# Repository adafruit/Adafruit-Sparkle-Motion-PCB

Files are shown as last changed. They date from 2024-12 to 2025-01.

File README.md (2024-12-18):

## Adafruit Sparkle Motion - All-In-One WLED and xLights Board

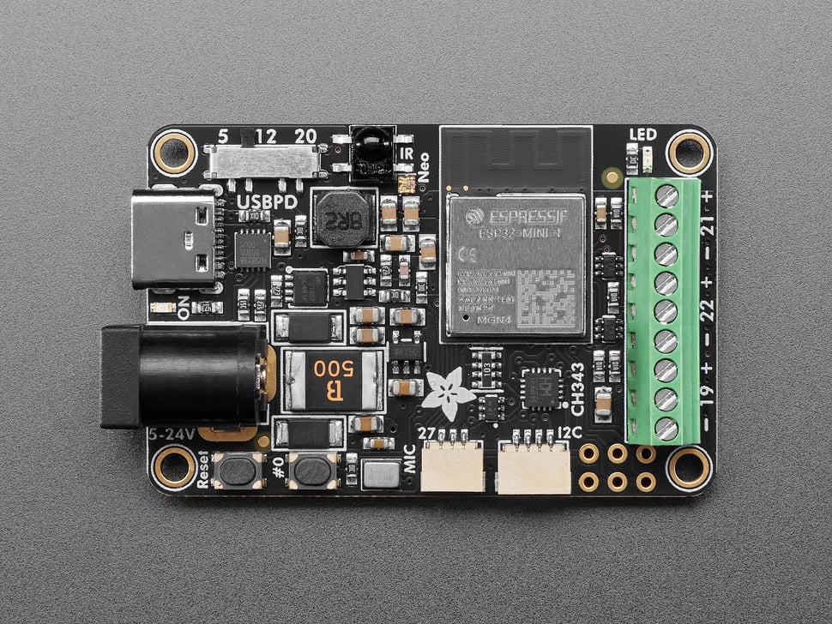
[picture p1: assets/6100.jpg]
<a href="http://www.adafruit.com/products/6100"><br/>
Click here to purchase one from the Adafruit shop</a>

PCB files for the Adafruit Sparkle Motion - All-In-One WLED and xLights Board

Format is EagleCAD schematic and board layout
* https://www.adafruit.com/product/6100

### Description

* Power via USB Type C PD with a slide switch that selects between 5, 12, and 20V (24V pixels can usually run fine at 20V) OR via a 2.1mm DC jack. With ideal diodes, it’s good for up to 5A from either.
* ESP32-Mini module with built-in or optional wFL antenna port. The classic ’32 has broad support, even if we’d prefer the ‘S2 or ‘S3.
* There are three output signal terminal block sets, with power and ground for each. They’ll be level-shifted to 5V.
* Built in I2S microphone (we’re still pondering this one).
* Stemma QT I2C port to connect external sensors/OLEDs/etc.; separate analog/digital input JST port.
* 1.3″x1.75″ / 33mm x 45mm size with mounting holes.

### License

Adafruit invests time and resources providing this open source design, please support Adafruit and open-source hardware by purchasing products from [Adafruit](https://www.adafruit.com)!

Designed by Limor Fried/Ladyada for Adafruit Industries.

Creative Commons Attribution/Share-Alike, all text above must be included in any redistribution. 
See license.txt for additional details.

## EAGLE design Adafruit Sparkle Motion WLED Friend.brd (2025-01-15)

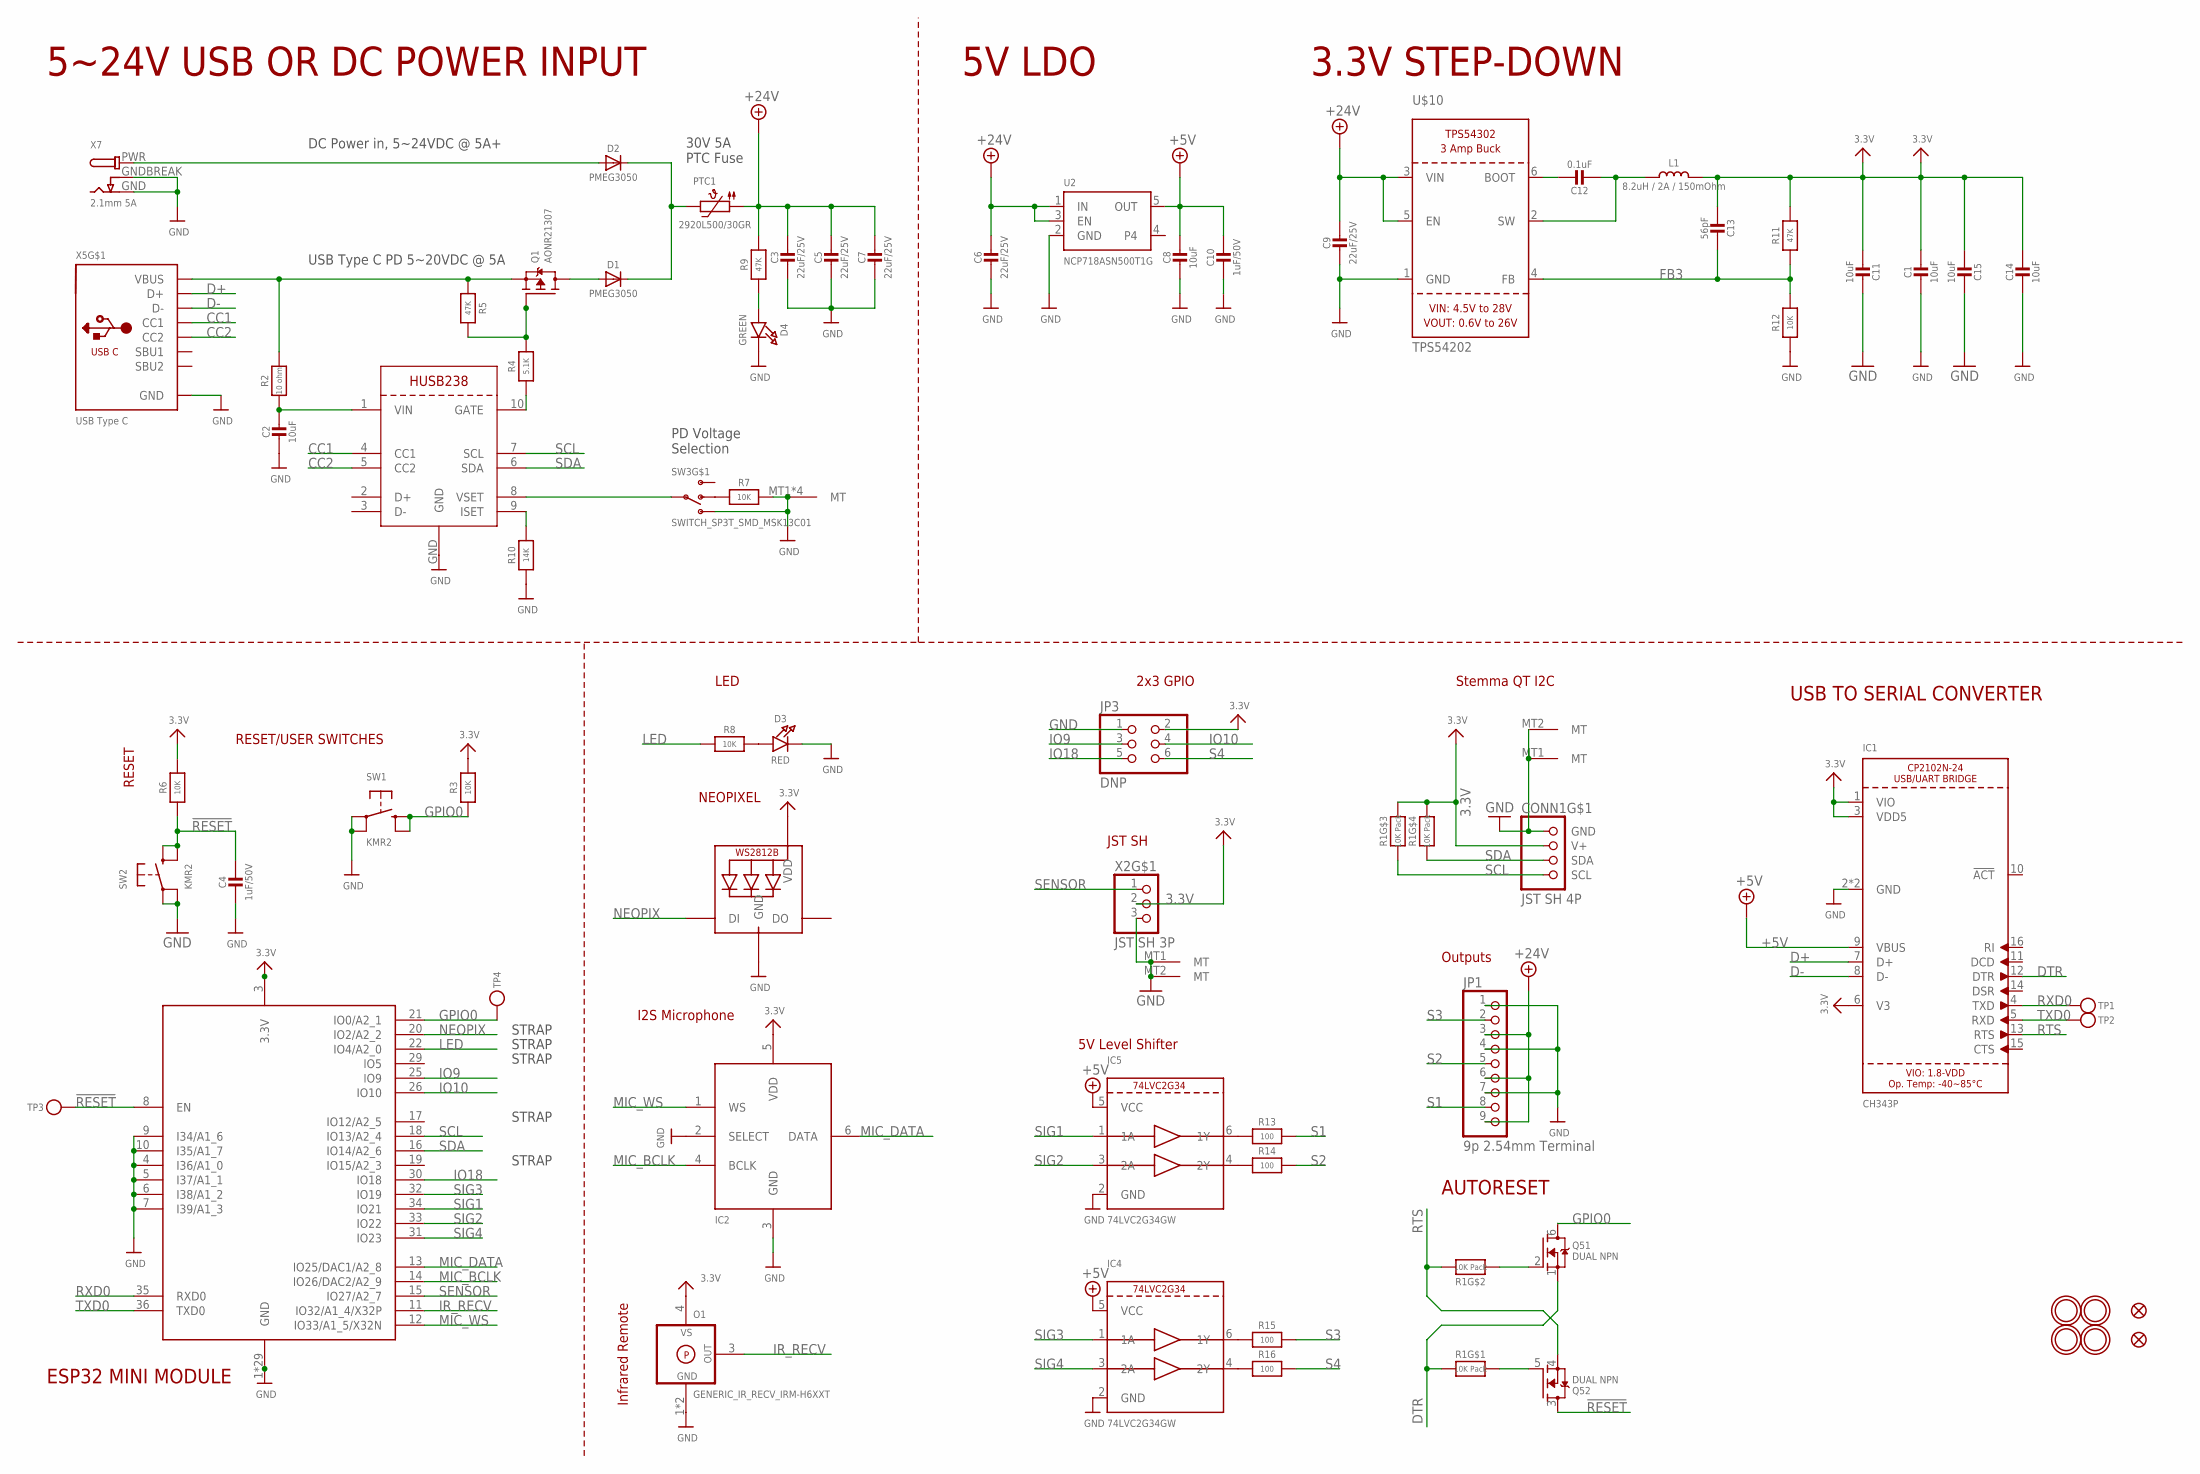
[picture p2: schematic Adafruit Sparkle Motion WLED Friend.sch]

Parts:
C1, C2, C8, C11, C14, C15: 10uF; 0805-NO
C3, C5, C6, C7, C9: 22uF/25V; 0805-NO
C4, C10: 1uF/50V; 0603-NO
C12: 0.1uF; 0603-NO
C13: 56pF; 0603-NO
CONN1: JST SH 4P; JST_SH4
D1, D2: PMEG3050; SOD-128
D3: RED; CHIPLED_0603_NOOUTLINE
D4: GREEN; CHIPLED_0603_NOOUTLINE
IC1: CH343P; QFN16_3MM
IC2: ICS-43434; SPH0645LM4H
IC4, IC5: 74LVC2G34GW; SC70-6L
JP1: 9p 2.54mm Terminal; 1X09_2.54MMTERMINAL
JP3: DNP; 2X03_ROUND_70MIL
L1: 8.2uH / 2A / 150mOhm; INDUCTOR_5X5MM_NR5040_NOTHERMALS
LED1: WS2812B_SK6805_1515; SK6805_1515
O1: GENERIC_IR_RECV_IRM-H6XXT; IRM-H6XXT
PTC1: 2920L500/30GR; PTC2920
Q1: AONR21307; POWERDI3333
Q5: DUAL NPN; SOT363; JLC_ROTATION 0
R1: 10K Pack; RESPACK_4X0603
R2: 10 ohm; 0603-NO
R3, R6, R7, R8, R12: 10K; 0603-NO
R4: 5.1K; 0603-NO
R5, R9, R11: 47K; 0603-NO
R10: 14K; 0603-NO
R13, R14, R15, R16: 100; 0603-NO
SW1, SW2: KMR2; BTN_RKB2_4.6X2.8
SW3: SWITCH_SP3T_SMD_MSK13C01; MSK-13C01
TP1, TP2, TP3, TP4: TESTPOINTROUND1.5MM; TESTPOINT_ROUND_1.5MM
U2: NCP718ASN500T1G; SOT23-5; JLC_ROTATION 0
U$10: TPS54202; SOT23-6
U$14, U$20, U$28, U$31: MOUNTINGHOLE2.5; MOUNTINGHOLE_2.5_PLATED
U$34, U$35: FIDUCIAL_1MM
X2: JST SH 3P; JST_SH3
X3: HUSB238; DFN10_3X3MM
X4: ESP32-MINI-1
X5: USB Type C; USB_C_CUSB31-CFM2AX-01-X
X7: 2.1mm 5A; DCJACK_2MM_PTH

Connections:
3.3V: C1.1, C11.1, C13.2, C14.1, C15.1, CONN1.2 (V+), IC1.1 (VIO), IC1.3 (VDD5), IC1.6 (V3), IC2.5 (VDD), JP3.2, L1.P$2 (2), LED1.2 (VDD), O1.4 (VS), R1.5 (2), R1.6 (2), R3.2, R6.2, R11.2, X2.2, X4.3 (3.3V)
!RESET: C4.1, Q5.3 (D), R6.1, SW2.B (S), SW2.B' (S1), TP3.P$1, X4.8 (EN)
+5V: C8.1, C10.1, IC1.9 (VBUS), IC4.5 (VCC), IC5.5 (VCC), U2.5 (OUT)
+24V: C3.1, C5.1, C6.1, C7.1, C9.1, JP1.3, JP1.6, JP1.9, PTC1.P$1 (1), R9.2, U2.1 (IN), U2.3 (EN), U$10.3 (VIN), U$10.5 (EN)
CC1: X3.4 (CC1), X5.A5 (CC1)
CC2: X3.5 (CC2), X5.B5 (CC2)
D+: IC1.7 (D+), X5.A6 (D+), X5.B6 (D+)
D-: IC1.8 (D-), X5.A7 (D-), X5.B7 (D-)
DTR: IC1.12 (DTR), Q5.1 (S), R1.1
FB3: C13.1, R11.1, R12.2, U$10.4 (FB)
GND: C1.2, C2.2, C3.2, C4.2, C5.2, C6.2, C7.2, C8.2, C9.2, C10.2, C11.2, C14.2, C15.2, CONN1.1 (GND), CONN1.MT1 (MT), CONN1.MT2 (MT), D3.C, D4.C, IC1.2 (GND), IC1.THERMAL (GND), IC2.2 (SELECT), IC2.3 (GND), IC4.2 (GND), IC5.2 (GND), JP1.1, JP1.4, JP1.7, JP3.1, LED1.4 (GND), O1.1 (GND), O1.2 (GND), R7.1, R10.1, R12.1, SW1.A, SW1.A' (P1), SW2.A, SW2.A' (P1), SW3.4 (3), SW3.MT1 (MT), SW3.MT2 (MT), SW3.MT3 (MT), SW3.MT4 (MT), U2.2 (GND), U$10.1 (GND), X2.3, X2.MT1 (MT), X2.MT2 (MT), X3.GND, X4.1 (GND), X4.2 (GND), X4.4 (I36/A1_0), X4.5 (I37/A1_1), X4.6 (I38/A1_2), X4.7 (I39/A1_3), X4.9 (I34/A1_6), X4.10 (I35/A1_7), X4.27 (GND), X4.38 (GND), X4.39 (GND), X4.40 (GND), X4.41 (GND), X4.42 (GND), X4.43 (GND), X4.44 (GND), X4.45 (GND), X4.46 (GND), X4.47 (GND), X4.48 (GND), X4.49 (GND), X4.50 (GND), X4.51 (GND), X4.52 (GND), X4.53 (GND), X4.54 (GND), X4.55 (GND), X4.56 (GND), X4.57 (GND), X4.58 (GND), X4.59 (GND), X4.60 (GND), X4.61 (GND), X4.62 (GND), X4.63 (GND), X5.A1B12 (GND), X5.B1A12 (GND), X7.GND, X7.GNDBREAK
GPIO0: Q5.6 (D), R3.1, SW1.B (S), SW1.B' (S1), TP4.P$1, X4.21 (IO0/A2_1)
IO9: JP3.3, X4.25 (IO9)
IO10: JP3.4, X4.26 (IO10)
IO18: JP3.5, X4.30 (IO18)
IR_RECV: O1.3 (OUT), X4.11 (IO32/A1_4/X32P)
LED: R8.1, X4.22 (IO4/A2_0)
MIC_BCLK: IC2.4 (BCLK), X4.14 (IO26/DAC2/A2_9)
MIC_DATA: IC2.6 (DATA), X4.13 (IO25/DAC1/A2_8)
MIC_WS: IC2.1 (WS), X4.12 (IO33/A1_5/X32N)
unnamed: D3.A, R8.2
unnamed: C2.1, R2.1, X3.1 (VIN)
unnamed: Q1.4 (G), R4.2, R5.2
unnamed: R4.1, X3.10 (GATE)
unnamed: SW3.3, X3.8 (VSET)
unnamed: R7.2, SW3.2
unnamed: Q5.5 (G), R1.8 (2)
unnamed: Q5.2 (G), R1.2 (1)
unnamed: D2.A, X7.PWR
unnamed: IC5.6 (1Y), R13.1
unnamed: IC5.4 (2Y), R14.1
unnamed: R10.2, X3.9 (ISET)
unnamed: D1.C, D2.C, PTC1.P$2 (2)
unnamed: D1.A, Q1.5678 (D)
unnamed: D4.A, R9.1
unnamed: C12.1, U$10.6 (BOOT)
unnamed: C12.2, L1.P$1 (1), U$10.2 (SW)
unnamed: IC4.6 (1Y), R15.1
unnamed: IC4.4 (2Y), R16.1
NEOPIX: LED1.1 (DI), X4.20 (IO2/A2_2)
RTS: IC1.13 (RTS), Q5.4 (S), R1.7 (2)
RXD0: IC1.4 (TXD), TP1.P$1, X4.35 (RXD0)
S1: JP1.8, R13.2
S2: JP1.5, R14.2
S3: JP1.2, R15.2
S4: JP3.6, R16.2
SCL: CONN1.4 (SCL), R1.3 (1), X3.7 (SCL), X4.18 (IO13/A2_4)
SDA: CONN1.3 (SDA), R1.4 (1), X3.6 (SDA), X4.16 (IO14/A2_6)
SENSOR: X2.1, X4.15 (IO27/A2_7)
SIG1: IC5.1 (1A), X4.34 (IO21)
SIG2: IC5.3 (2A), X4.33 (IO22)
SIG3: IC4.1 (1A), X4.32 (IO19)
SIG4: IC4.3 (2A), X4.31 (IO23)
TXD0: IC1.5 (RXD), TP2.P$1, X4.36 (TXD0)
VBUS1: Q1.1 (S), Q1.2 (S), Q1.3 (S), R2.2, R5.1, X5.A4B9 (VBUS), X5.B4A9 (VBUS)

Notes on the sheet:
5~24V USB OR DC POWER INPUT
RESET
LED
NEOPIXEL
ESP32 MINI MODULE
RESET/USER SWITCHES
AUTORESET
USB TO SERIAL CONVERTER
DC Power in, 5~24VDC @ 5A+
USB Type C PD 5~20VDC @ 5A
30V 5A PTC Fuse
PD Voltage Selection
5V LDO
3.3V STEP-DOWN
STRAP
I2S Microphone
Infrared Remote
2x3 GPIO
JST SH
5V Level Shifter
Stemma QT I2C
Outputs

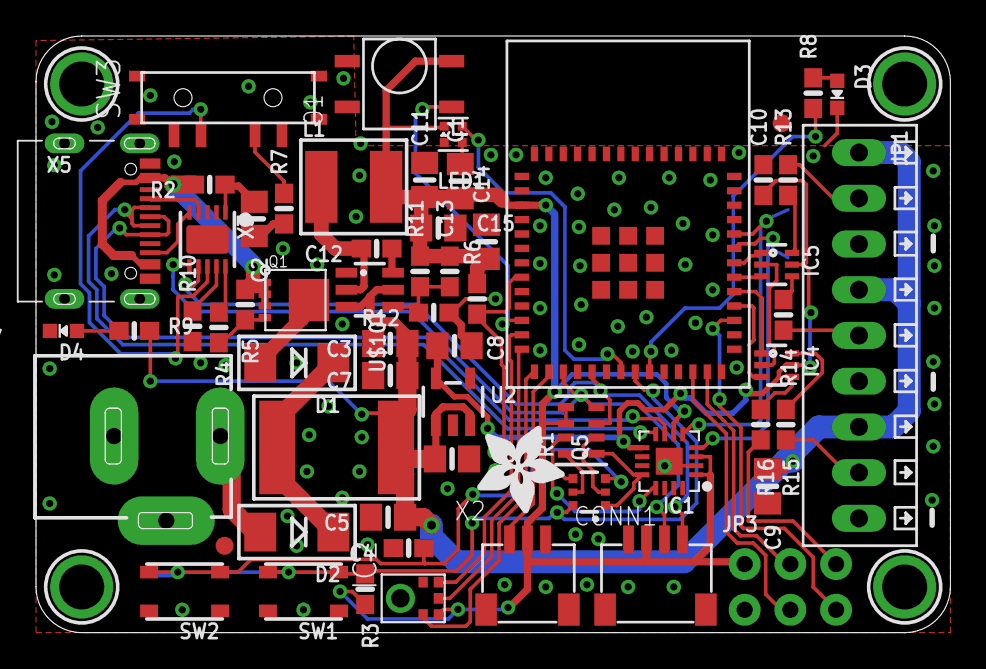
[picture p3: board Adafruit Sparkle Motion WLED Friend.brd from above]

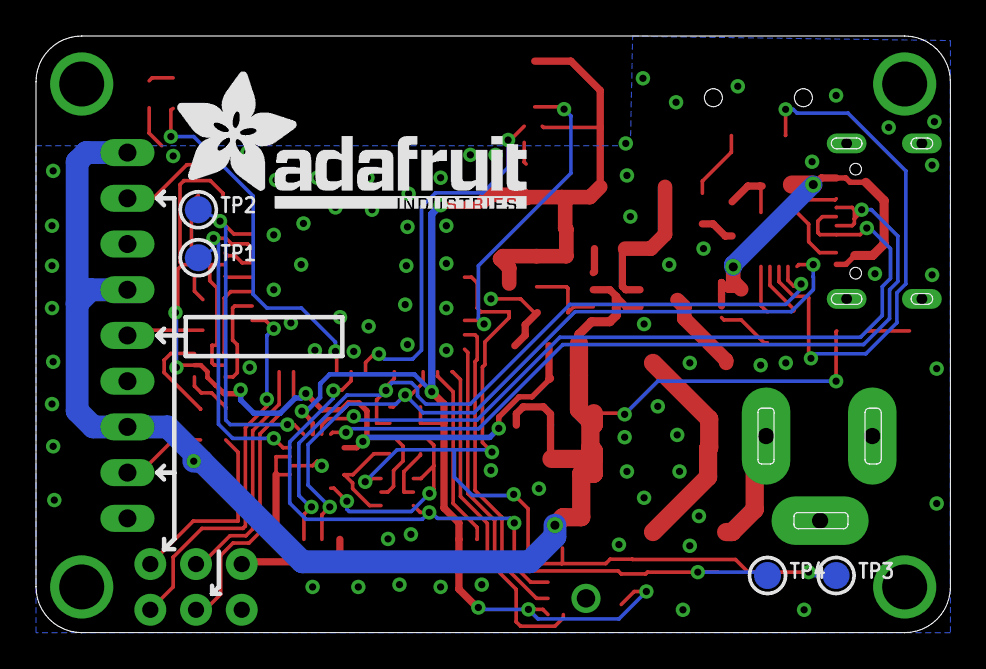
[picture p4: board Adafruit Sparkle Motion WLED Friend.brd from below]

Board: 2 copper layers, 50.8 x 33.1 mm, 123 parts (36 on the bottom side), 55 nets.

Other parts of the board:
PLABEL0: PLABEL0
PLABEL1: PLABEL1
PLABEL2: PLABEL2
PLABEL3: PLABEL3
PLABEL4: PLABEL4
PLABEL6: PLABEL6
PLABEL7: PLABEL7
PLABEL8: PLABEL8
PLABEL9: PLABEL9
PLABEL10: PLABEL10
PLABEL11: PLABEL11
PLABEL13: PLABEL13
PLABEL14: PLABEL14
PLABEL16: PLABEL16
PLABEL17: PLABEL17
PLABEL19: PLABEL19
PLABEL20: PLABEL20
PLABEL21: PLABEL21
PLABEL22: PLABEL22
PLABEL23: PLABEL23
PLABEL24: PLABEL24
PLABEL25: PLABEL25
PLABEL26: PLABEL26
PLABEL27: PLABEL27
PLABEL28: PLABEL28
PLABEL29: PLABEL29
PLABEL30: PLABEL30
PLABEL31: PLABEL31
PLABEL32: PLABEL32
PLABEL33: PLABEL33
PLABEL34: PLABEL34
PLABEL35: PLABEL35
PLABEL36: PLABEL36
PLABEL37: PLABEL37
PLABEL38: PLABEL38
PLABEL39: PLABEL39
PLABEL40: PLABEL40
PLABEL41: PLABEL41
PLABEL42: PLABEL42
PLABEL43: PLABEL43
PLABEL44: PLABEL44
PLABEL45: PLABEL45
PLABEL46: PLABEL46
PLABEL47: PLABEL47
PLABEL48: PLABEL48
PLABEL49: PLABEL49
PLABEL50: PLABEL50
PLABEL51: PLABEL51
PLABEL52: PLABEL52
PLABEL53: PLABEL53
PLABEL54: PLABEL54
PLABEL55: PLABEL55
PLABEL56: PLABEL56
U$46: ADAFRUIT_5MM
U$50: ADAFRUIT_TEXT_20MM

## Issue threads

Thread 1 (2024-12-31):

Voltage regulation?

mikeholczer, 2024-12-31:
Sorry, if this is not the right place for this question, but looking at the schematic, am I right that the voltage switch is to set the PD for the USB-C input, but not to regulate the voltage from the barrel connector? I'd be interested in powering it from a 13.4V battery on my RV. So want to make sure I'd need to drop the voltage down to 12V in front of the board to use it with 12V neopixel strips.

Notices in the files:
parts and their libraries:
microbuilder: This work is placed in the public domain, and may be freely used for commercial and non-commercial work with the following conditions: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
